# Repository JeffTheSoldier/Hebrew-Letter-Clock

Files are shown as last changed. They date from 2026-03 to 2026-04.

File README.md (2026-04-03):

# 🕰️ Hebrew Letter Clock

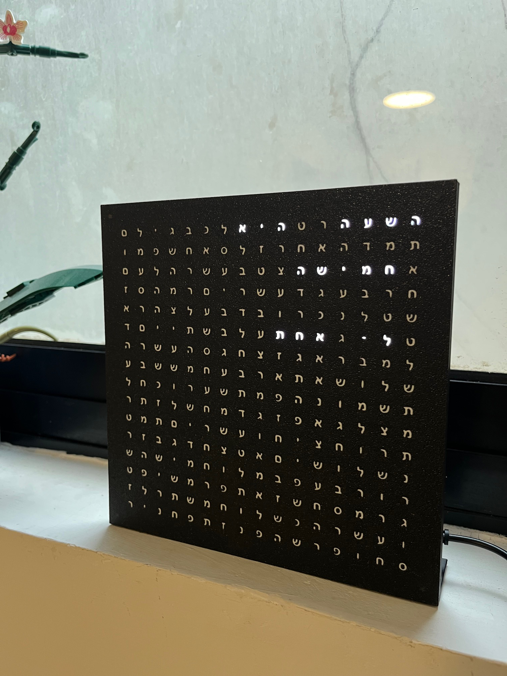
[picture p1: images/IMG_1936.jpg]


A sleek, 3D-printed word clock that tells time in Hebrew using an Arduino Nano and a 16x16 RGB LED matrix. This version includes a manual skip button to set the time in 5-minute increments.

---

## 📦 Parts List

### Electronics
| Component | Description | Link |
| :--- | :--- | :--- |
| **LED Matrix** | 16x16 RGB WS2812B LED Matrix | [AliExpress](https://he.aliexpress.com/item/1005003901833984.html) |
| **Microcontroller** | Arduino Nano (ATmega328P) | [AliExpress](https://he.aliexpress.com/item/1005007066680464.html) |
| **Push Button** | Momentary Tactile Button (for time setting) | - |
| **Power Supply** | 5V 3A DC Power Adapter | [AliExpress](https://he.aliexpress.com/item/32961533195.html) |
| **Power Port** | 5.5mm x 2.1mm Female Jack | [AliExpress](https://he.aliexpress.com/item/1005006755773620.html) |
| **Resistor** | 220 Ohm (for LED data line protection) | - |

### Hardware & Tools
* **3D Printer:** (AMS/Multi-material recommended for the front panel)
* **Fasteners:** M3 Screws & M3 Heat-set inserts
* **Wiring:** Jumper wires & [Soldering Tin](https://he.aliexpress.com/item/1005006222917407.html)
* **Tools:** Soldering Iron, Hex keys

---

## 🔌 Wiring Diagram

| From (Component) | Pin | To (Component) | Pin | Notes |
| :--- | :--- | :--- | :--- | :--- |
| **Power Jack** | (+) 5V | **LED Matrix** & **Arduino** | 5V / VIN | Connected in parallel |
| **Power Jack** | (-) GND | **LED Matrix** & **Arduino** | GND | Connected in parallel |
| **Arduino** | **D3** | **LED Matrix** | DIN | Via 220Ω Resistor |
| **Arduino** | **D2** | **Push Button** | Leg 1 | Uses internal `INPUT_PULLUP` |
| **Push Button** | Leg 2 | **Arduino** | **GND** | Completes circuit to Ground |

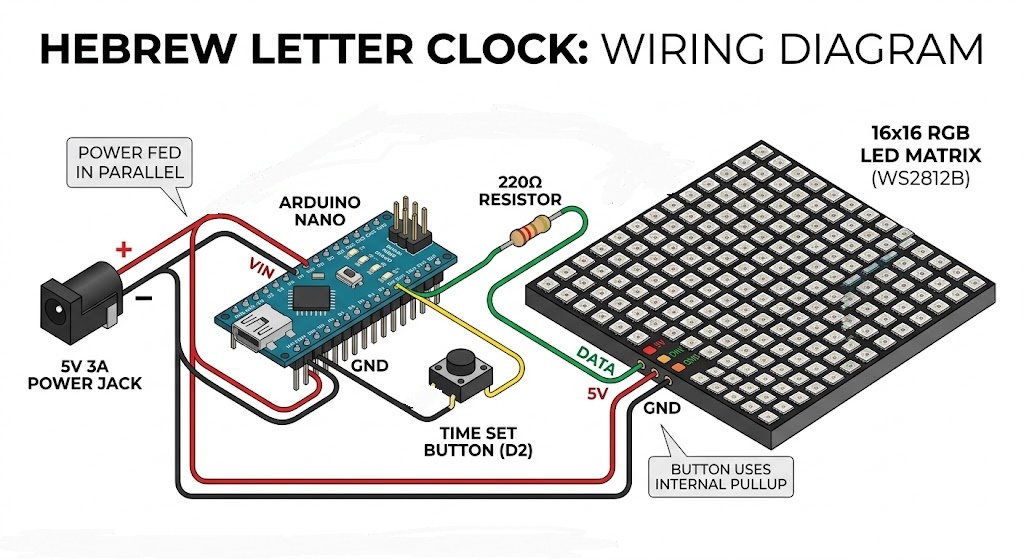
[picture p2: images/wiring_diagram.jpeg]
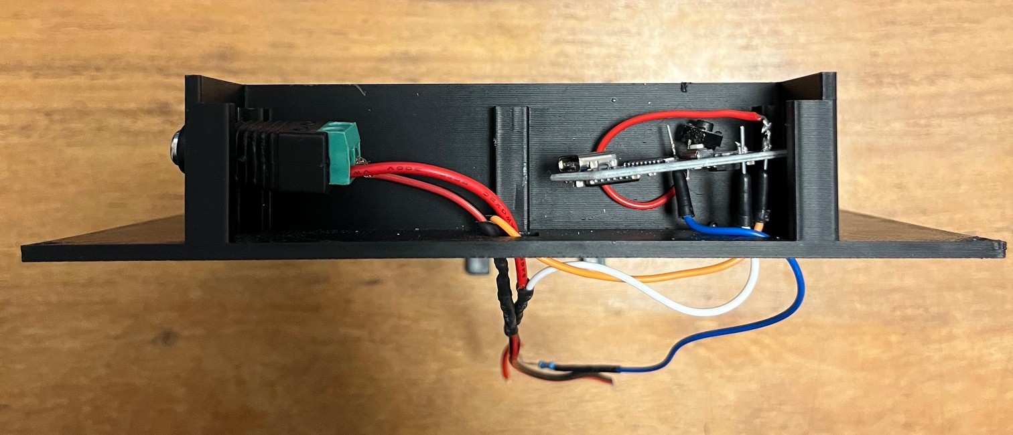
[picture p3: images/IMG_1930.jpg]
 

> **Note:** The button does not require an external resistor. The 220Ω resistor should be soldered inline between the Arduino D3 pin and the LED Matrix Data Input to protect the first LED from voltage spikes.

---

## 🏗 Assembly Guide

1. **Front Panel:** Place the 3D-printed front panel face down (letters facing the table).
2. **Inserts:** Press 4 heat-set inserts into the corners of the front panel.
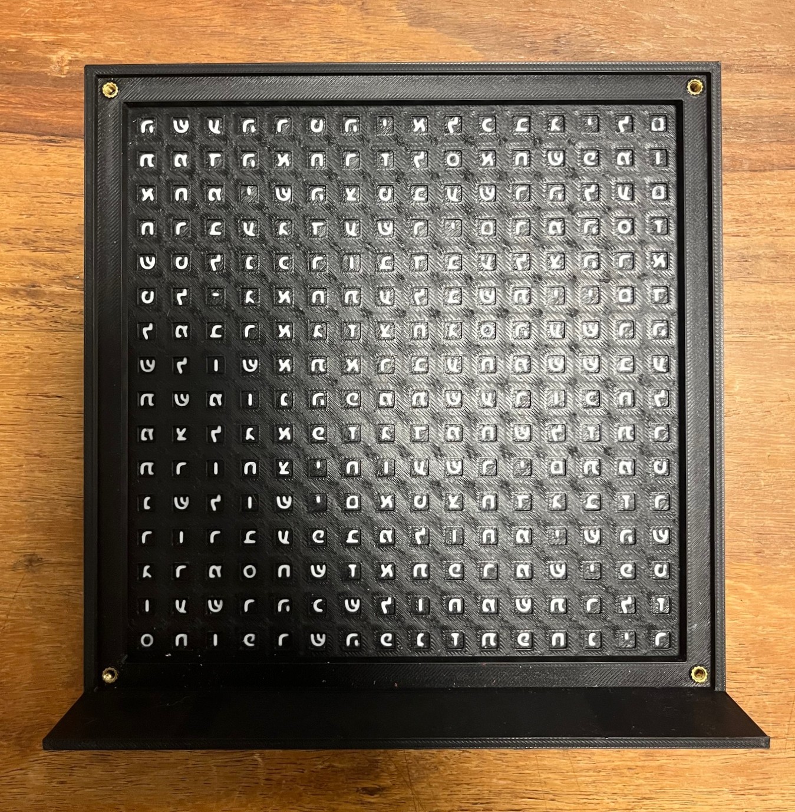
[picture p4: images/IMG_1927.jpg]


3. **Matrix:** Align the **LED Matrix** on the front panel. Ensure wires are positioned at the bottom.
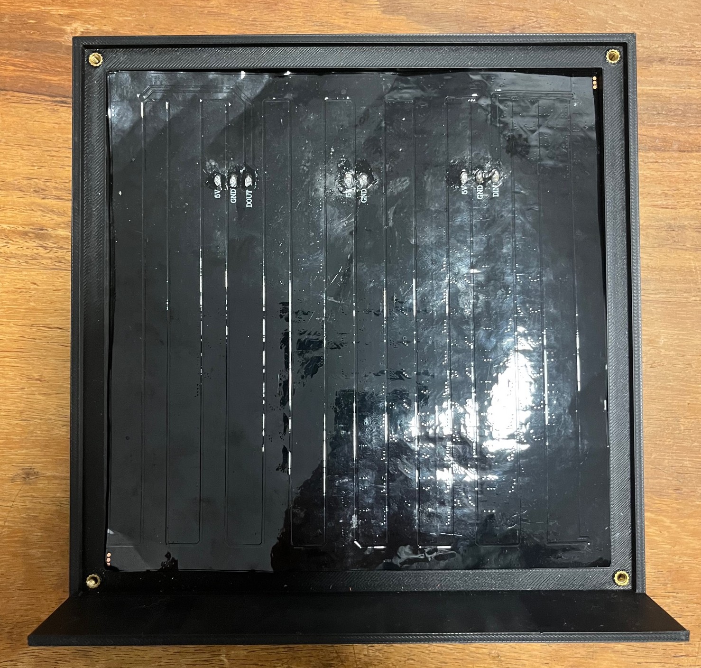
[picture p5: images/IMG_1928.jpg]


4. **Grid:** Drop the **Inner Grid** on top of the matrix. This prevents light from "bleeding" into neighboring letters.
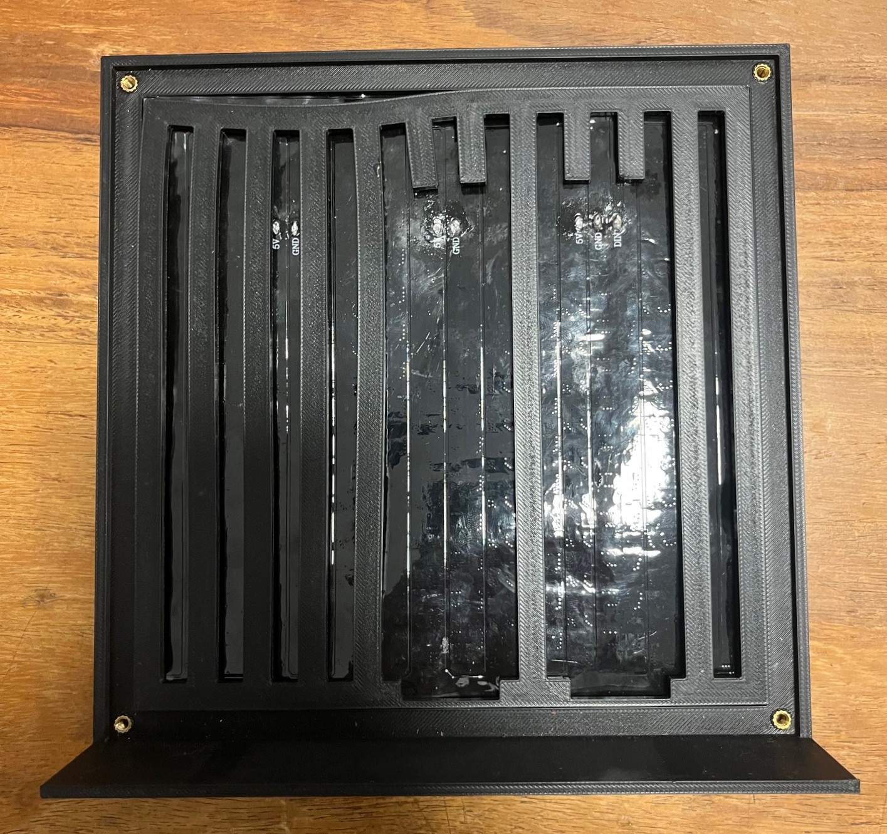
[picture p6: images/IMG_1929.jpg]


5. **Back Panel:** Place the back panel over the grid and thread the matrix wires through the center hole.
6. **Secure:** Screw the back panel into the front panel inserts.
7. **Housing:** Install heat-set inserts for the final back cover.
8. **Electronics:** Mount the **Arduino**, **Power Jack**, and **Push Button** into the rear housing.
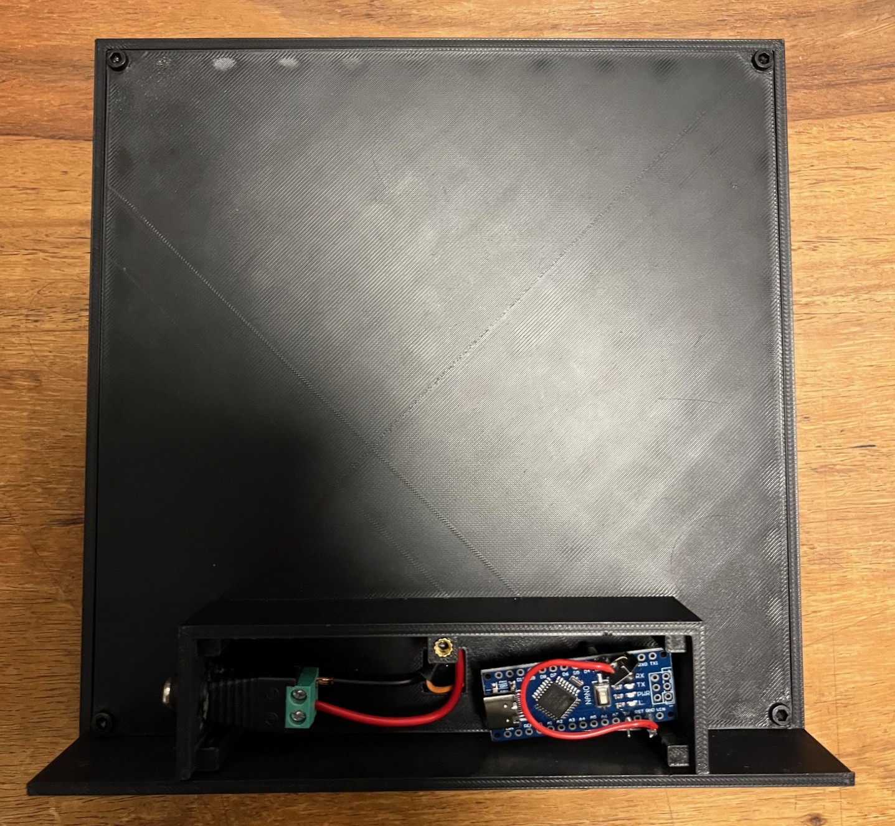
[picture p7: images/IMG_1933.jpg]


9. **Close:** Wire everything up according to the diagram and screw the **Back Cover** shut.

---

## ⚙️ How it Works

* **Automatic Mode:** The clock advances by 5 minutes every 300,000ms (5 minutes).
* **Manual Override:** Pressing the button immediately advances the clock by 5 minutes and **resets** the internal timer.
* **Hebrew Logic:** The hour cycles forward when the minutes reach the 40-minute mark.
* **Debug:** When connected via USB, the Serial Monitor (9600 baud) will print `"test"` every time the button is successfully pressed.

---

## 🛠 Software Requirements

This project requires the following Arduino library:
* `FastLED` 

---

*Created by JeffTheSoldier.*

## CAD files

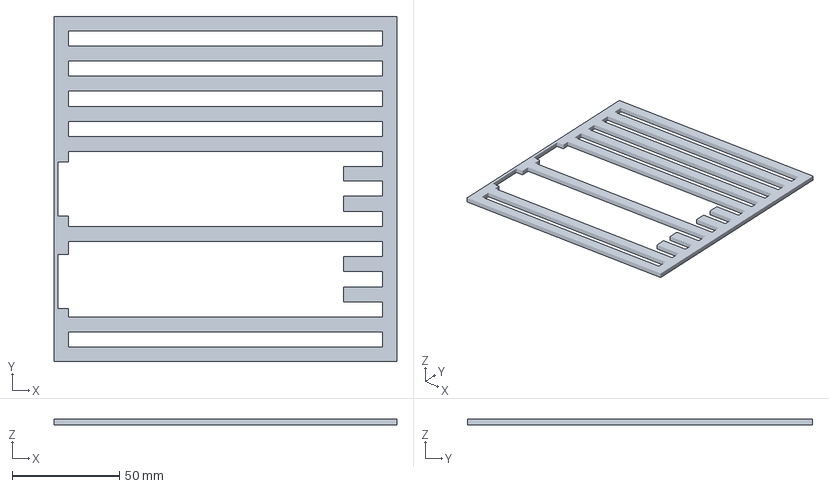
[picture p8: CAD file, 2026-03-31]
Inner_grid_print_file.3mf
159.6 x 160.6 x 3.00 mm

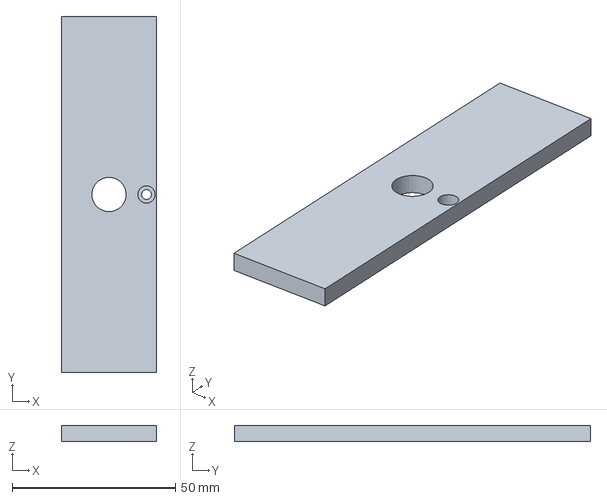
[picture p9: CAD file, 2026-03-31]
Back_cover_print_file.3mf
29.2 x 109.2 x 5.00 mm

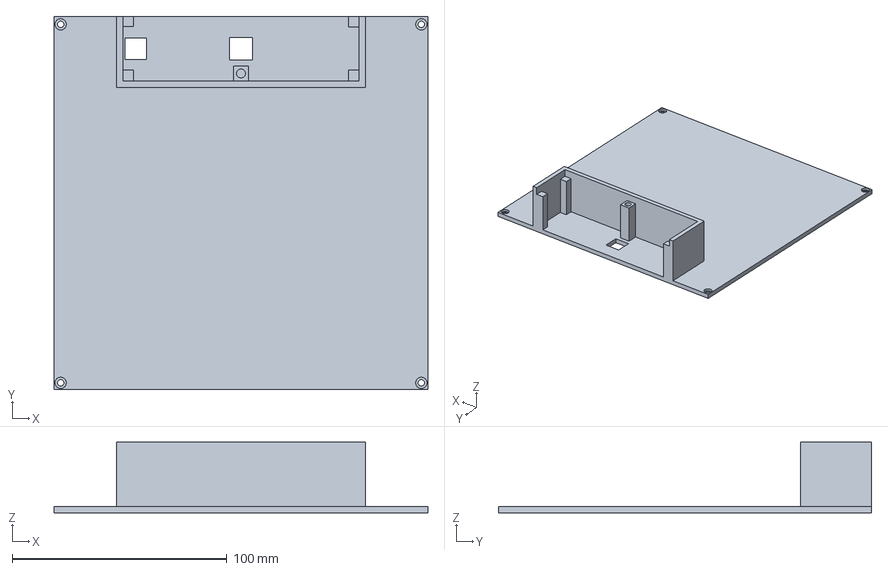
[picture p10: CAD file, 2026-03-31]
Back_panel_print_file.3mf
174.2 x 173.8 x 33.0 mm

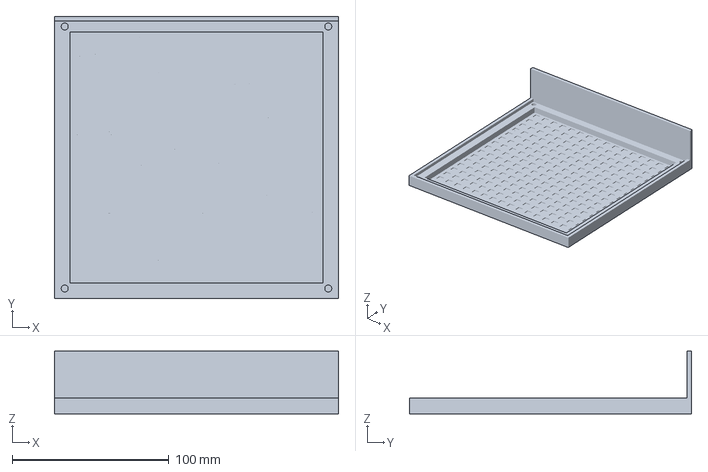
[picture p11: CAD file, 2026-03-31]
Front_panel_print_file.3mf
181.0 x 180.0 x 40.0 mm

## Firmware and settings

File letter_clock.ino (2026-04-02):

#include "FastLED.h"

#define NUM_LEDS 256
#define DATA_PIN 3
#define BUTTON_PIN 2
#define INTERVAL 300000 

CRGB leds[NUM_LEDS];

int hour = 0;
int minuteStep = 0; 
unsigned long lastUpdateTime = 0; 

// Button state variables
bool lastButtonState = HIGH;
unsigned long lastDebounceTime = 0;
unsigned long debounceDelay = 50; 

int hours[12][3] = { {9,5,3}, {1,5,5}, {12,7,4}, {6,7,4}, {3,7,3}, {2,7,2}, {0,7,3}, {10,8,5}, {5,8,3}, {1,6,3}, {9,5,3}, {1,5,5} };
int minutes[11][3] = { {1,12,6}, {11,14,5}, {11,12,4}, {3,10,6}, {3,10,5}, {10,10,4}, {9,11,6}, {5,3,5}, {12,3,3}, {3,2,4}, {10,2,5} };

int XY(int x, int y) {
  if (x % 2 == 0) return x * 16 + y;
  else return x * 16 + (15 - y);
}

void clearWords() {
  FastLED.clear();
  for (int i = 12; i < 16; i++) leds[XY(i,0)] = CRGB::White; 
  for (int i = 7; i < 10; i++) leds[XY(i,0)] = CRGB::White;  
}

void advanceTime() {
  minuteStep++;
  if (minuteStep == 8) { 
    hour = (hour + 1) % 12;
  }
  if (minuteStep > 11) {
    minuteStep = 0;
  }
  updateDisplay();
}

void updateDisplay() {
  clearWords();
  for (int j = 0; j < hours[hour][2]; j++) {
    leds[XY(hours[hour][0] + j, hours[hour][1])] = CRGB::White;
  }
  if (hour > 9) {
    for (int j = 0; j < 4; j++) leds[XY(j,6)] = CRGB::White;
  }
  if (minuteStep > 0) {
    int i = minuteStep - 1;
    for (int j = 0; j < minutes[i][2]; j++) {
      leds[XY(minutes[i][0] + j, minutes[i][1])] = CRGB::White;
    }
    if (i == 4 || i == 6) {
      for (int k = 4; k < 8; k++) leds[XY(k,14)] = CRGB::White;
    }
    if (i > 6) {
      for (int l = 13; l < 15; l++) leds[XY(l,5)] = CRGB::White;
    }
  }
  FastLED.show();
}

void setup() {
  Serial.begin(9600);                // <--- Start Serial communication
  Serial.println("System Online");
  pinMode(BUTTON_PIN, INPUT_PULLUP); 
  FastLED.addLeds<WS2812B, DATA_PIN, RGB>(leds, NUM_LEDS);
  FastLED.setMaxPowerInVoltsAndMilliamps(5, 2000);
  FastLED.setBrightness(20);
  updateDisplay();
}

void loop() {
  unsigned long currentTime = millis();

  // 1. Automatic Timer
  if (currentTime - lastUpdateTime >= INTERVAL) {
    lastUpdateTime = currentTime; 
    advanceTime();
  }

  // 2. Fixed Button Logic
  int reading = digitalRead(BUTTON_PIN);

  // If the button state changed (due to noise or pressing)
  if (reading != lastButtonState) {
    lastDebounceTime = currentTime; // Reset the timer
  }

  // Only act if the state has been stable for longer than the debounce delay
  if ((currentTime - lastDebounceTime) > debounceDelay) {
    // If the button IS pressed (LOW) and we haven't handled this press yet
    static bool isHandled = false;
    
    if (reading == LOW && !isHandled) {
      Serial.println("test"); 
      advanceTime();
      lastUpdateTime = currentTime; 
      isHandled = true; // Mark as handled so it doesn't repeat
    } 
    // Reset the handler when the button is released (HIGH)
    else if (reading == HIGH) {
      isHandled = false;
    }
  }

  lastButtonState = reading; // Save the reading for next time
}
